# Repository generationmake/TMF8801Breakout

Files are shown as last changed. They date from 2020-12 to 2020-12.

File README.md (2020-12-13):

# TMF8801Breakout
Breakout board for the ams TMF8801 1D time-of-flight sensor

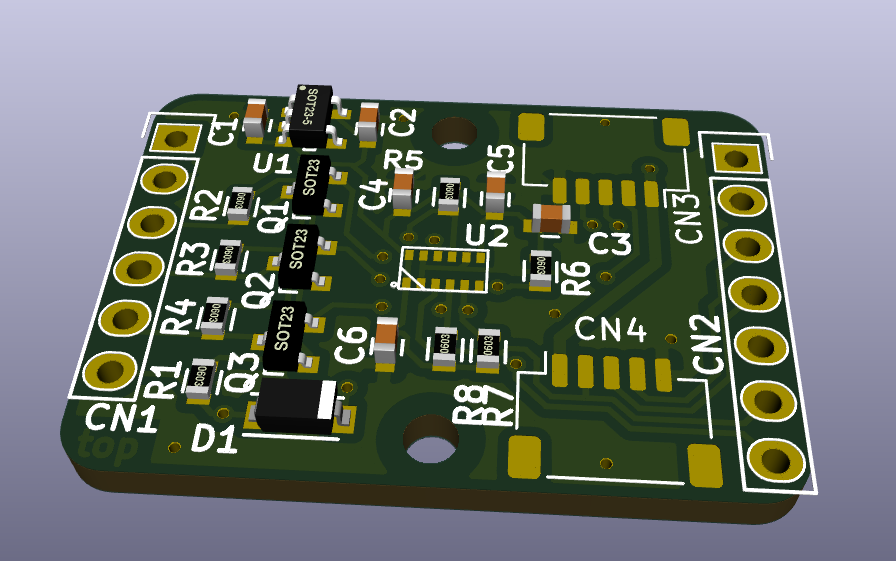
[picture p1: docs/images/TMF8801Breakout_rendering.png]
TMF8801Breakout rendering


## Pinout

### CN1 and CN2

This is a regular 0.1-inch pin header.

| pin number | signal on CN1 | signal on CN2|
|:---:|:---:|:---:|
| 1 | VCC | VCC |
| 2 | GND | GND |
| 3 | I2C_SDA | I2C_SDA |
| 4 | I2C_SCL | I2C_SCL |
| 5 | INT | INT |
| 6 | ENABLE | GPIO0 |
| 7 | not available | GPIO1 |

Several TMF8801Breakout boards can be used by connecting CN1 to CN2 of the previous board. GPIO0 is used to enabled the following TMF8801 and thus giving the possibility to change the I2C address of each device one after another.

### CN3 and CN4

This is Arduino ESLOV connector. JST SH 1mm 5-pin.

| pin number | signal on CN3 | signal on CN4|
|:---:|:---:|:---:|
| 1 | VCC | VCC |
| 2 | GND | GND |
| 3 | I2C_SDA | I2C_SDA |
| 4 | I2C_SCL | I2C_SCL |
| 5 | ENABLE | GPIO0 |

Several TMF8801Breakout boards can be used by connecting CN3 to CN4 of the previous board. GPIO0 is used to enabled the following TMF8801 and thus giving the possibility to change the I2C address of each device one after another.

This connector does not allow the use of interrupts.

## PCB

### Top

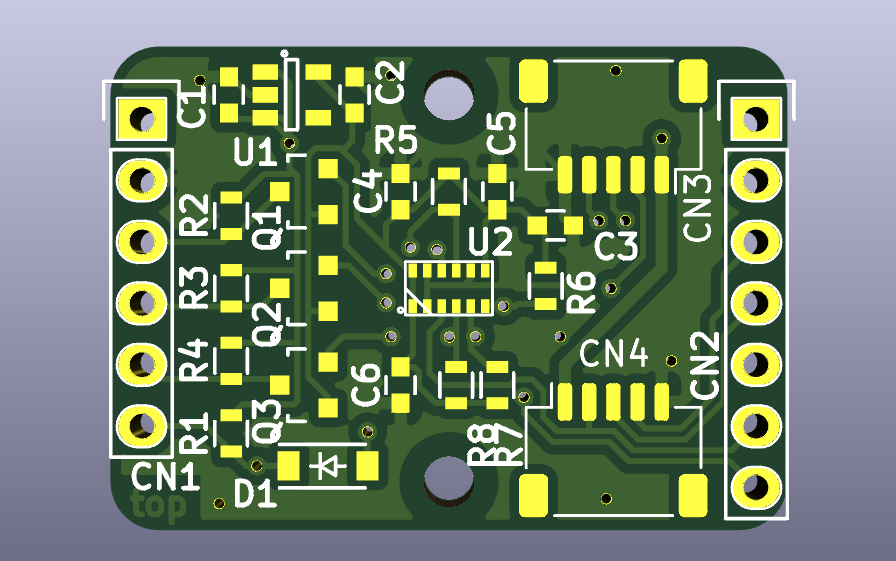
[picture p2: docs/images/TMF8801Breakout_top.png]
TMF8801Breakout PCB top


### Bottom

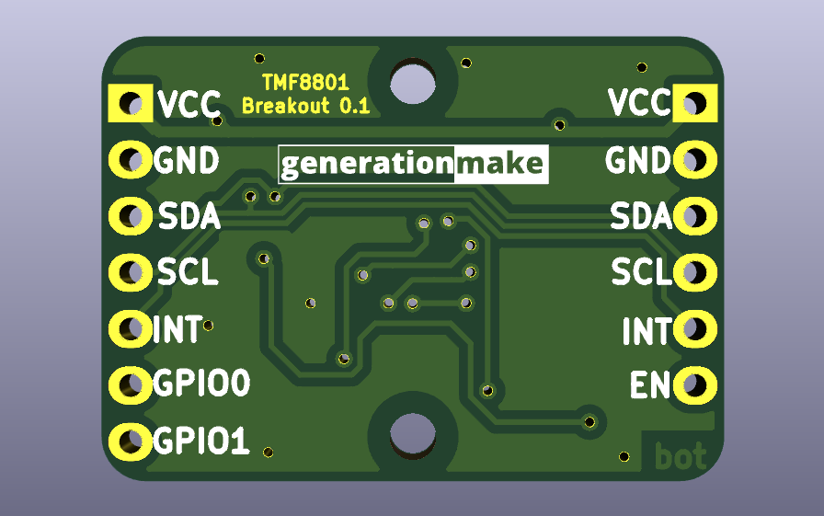
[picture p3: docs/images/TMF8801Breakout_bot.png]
TMF8801Breakout PCB bot


## Resources

### Datasheets

 * https://ams.com/documents/20143/36005/TMF8801_DS000648_5-01.pdf

### Arduino Libraries

* [107-Arduino-TMF8801](https://github.com/107-systems/107-Arduino-TMF8801)

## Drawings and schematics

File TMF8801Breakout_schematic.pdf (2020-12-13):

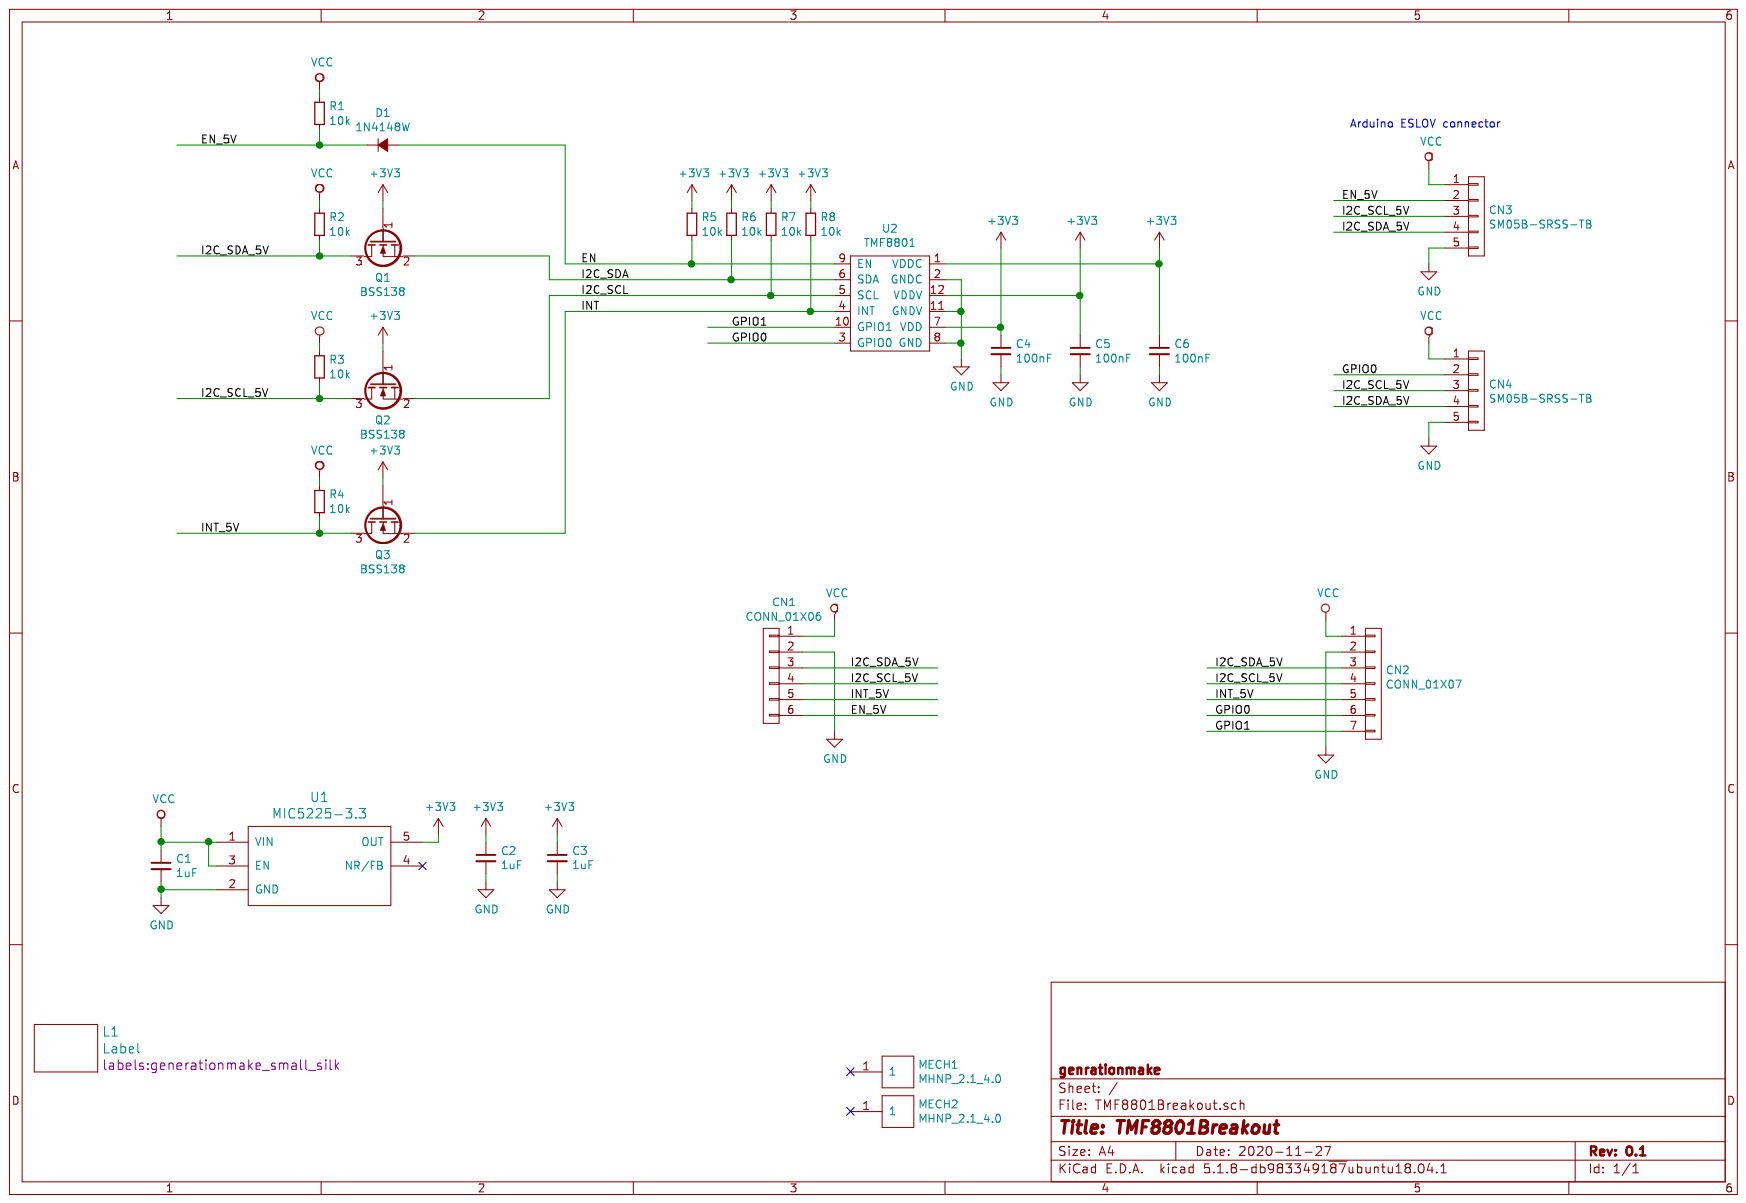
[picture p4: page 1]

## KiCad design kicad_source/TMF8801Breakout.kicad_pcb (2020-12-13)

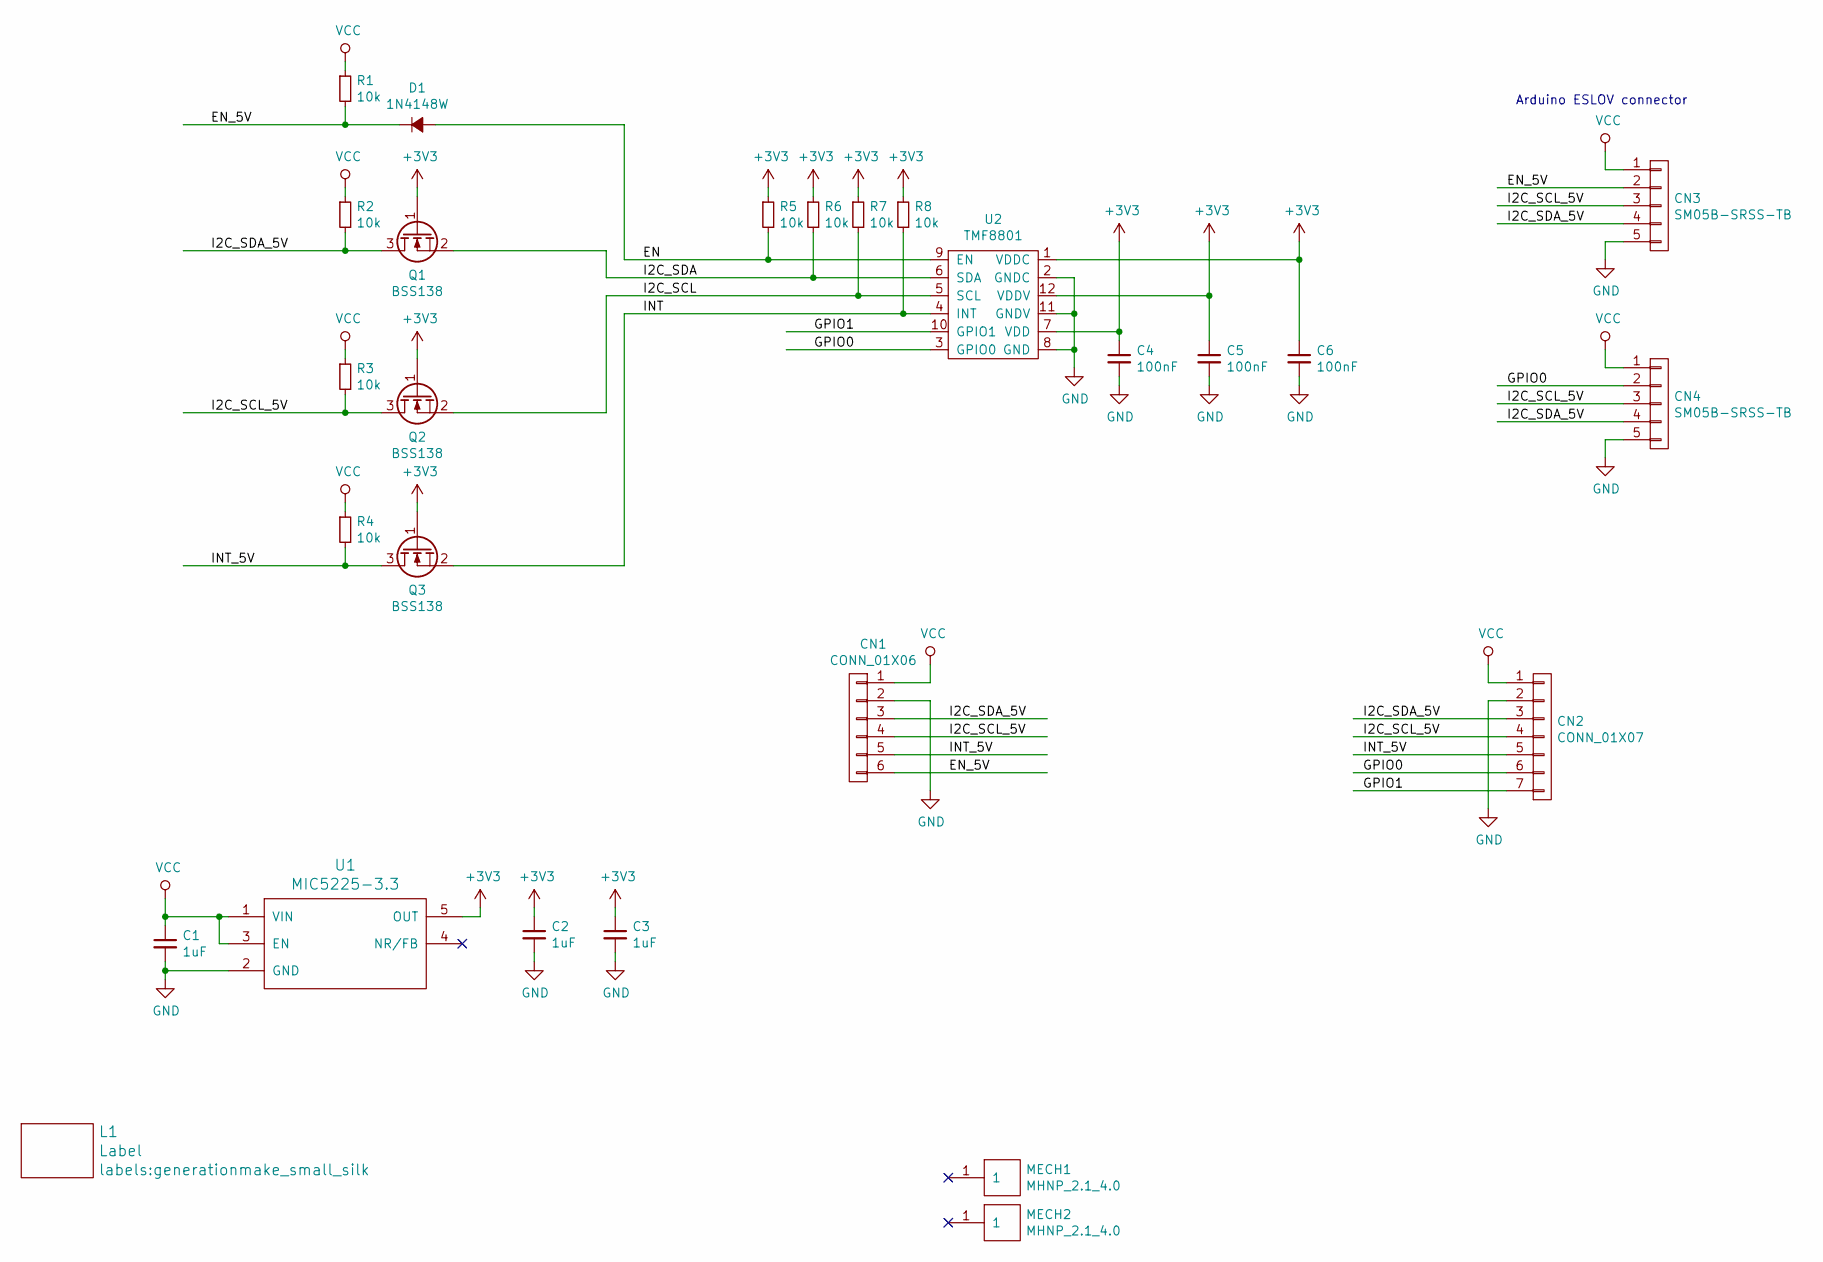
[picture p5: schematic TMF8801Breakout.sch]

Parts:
C1, C2, C3: 1uF; C_0603
C4, C5, C6: 100nF; C_0603
CN1: CONN_01X06; Pin_Header_Straight_1x06
CN2: CONN_01X07; Pin_Header_Straight_1x07
CN3, CN4: SM05B-SRSS-TB; JST_SH_SM05B-SRSS-TB_1x05-1MP_P1.00mm_Horizontal
D1: 1N4148W; SOD-123
L1: Label; generationmake_small_silk
MECH1, MECH2: MHNP_2.1_4.0; MH_210_400_NP
Q1, Q2, Q3: BSS138; SOT-23
R1, R2, R3, R4, R5, R6, R7, R8: 10k; R_0603
U1: MIC5225-3.3; SOT-23-5
U2: TMF8801

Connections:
+3V3: C2.1, C3.1, C4.1, C5.1, C6.1, Q1.1 (G), Q2.1 (G), Q3.1 (G), R5.1, R6.1, R7.1, R8.1, U1.5 (OUT), U2.1 (VDDC), U2.7 (VDD), U2.12 (VDDV)
/EN: D1.2 (A), R5.2, U2.9 (EN)
/EN_5V: CN1.6, CN3.2, D1.1 (K), R1.2
/GPIO0: CN2.6, CN4.2, U2.3 (GPIO0)
/GPIO1: CN2.7, U2.10 (GPIO1)
/I2C_SCL: Q2.2 (S), R7.2, U2.5 (SCL)
/I2C_SCL_5V: CN1.4, CN2.4, CN3.3, CN4.3, Q2.3 (D), R3.2
/I2C_SDA: Q1.2 (S), R6.2, U2.6 (SDA)
/I2C_SDA_5V: CN1.3, CN2.3, CN3.4, CN4.4, Q1.3 (D), R2.2
/INT: Q3.2 (S), R8.2, U2.4 (INT)
/INT_5V: CN1.5, CN2.5, Q3.3 (D), R4.2
GND: C1.2, C2.2, C3.2, C4.2, C5.2, C6.2, CN1.2, CN2.2, CN3.5, CN4.5, U1.2 (GND), U2.2 (GNDC), U2.8 (GND), U2.11 (GNDV)
VCC: C1.1, CN1.1, CN2.1, CN3.1, CN4.1, R1.1, R2.1, R3.1, R4.1, U1.1 (VIN), U1.3 (EN)

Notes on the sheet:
Arduino ESLOV connector

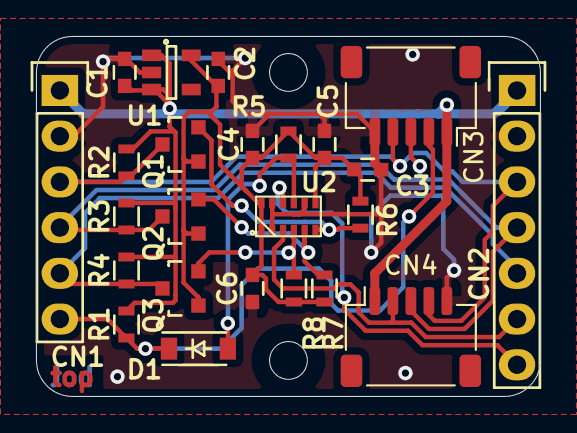
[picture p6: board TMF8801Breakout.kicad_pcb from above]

Board: 2 copper layers, 28.0 x 20.0 mm, 27 parts (1 on the bottom side), 13 nets.

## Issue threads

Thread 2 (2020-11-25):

Suggestion: Use ESLOV Connector standard

aentinger, 2020-11-25:
The ESLOV connector is mounted on various Arduino boards and shields (such as the [MKR GPS Shield](https://store.arduino.cc/arduino-mkr-gps-shield)). You can think of it as the QWIIC of Arduino. Details to its pinout and connector type are available under the **Documentation** tab of the MKR GPS Shield product page. There's also a link to the connectors [datasheet](https://content.arduino.cc/assets/ESLOV_connector.pdf).

Closed 2020-12-13.

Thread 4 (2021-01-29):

add serial resistors on GPIO0 and GPIO1

generationmake, 2021-01-29:
something like 100 Ohm to prevent damage if someone accidentialy connects hard levels.

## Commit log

2020-11-24 added kicad project
    [TMF8801Breakout.sch]
2020-11-25 added layout
    [TMF8801Breakout.kicad_pcb, TMF8801Breakout.sch]
2020-11-25 added images, added pdf schematic
2020-11-25 added Arduino ESLOV connector
    [TMF8801Breakout.kicad_pcb, TMF8801Breakout.sch]
2020-11-25 moved CN1 and CN1 into 0.1 inch grid, made pcb slightly smaller, performed DRC
    [TMF8801Breakout.kicad_pcb]
2020-11-25 updated images
    [TMF8801Breakout.kicad_pcb]
2020-11-27 added second ESLOV connector
    [TMF8801Breakout.kicad_pcb, TMF8801Breakout.sch]
